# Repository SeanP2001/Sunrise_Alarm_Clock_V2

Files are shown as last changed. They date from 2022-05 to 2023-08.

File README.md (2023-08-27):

# Sunrise Alarm Clock V2

## Table of Contents

* [Introduction](#introduction)
* [Brief](#brief)
* [Method of Operation](#method-of-operation)
  + [Setup](#setup)
  + [Main Screen](#main-screen)
  + [Menu Layout](#menu-layout)
* [Circuitry](#circuitry)
  + [Schematic](#schematic)
  + [PCB Design](#pcb-design)
* [Enclosure](#enclosure)
  + [CAD Enclosure](#cad-enclosure)
  + [3D Printed Enclosure](#3d-printed-enclosure)
* [Demonstration](#demonstration)
* [Further Work](#further-work)

## Introduction

In my first year of university, I made a sunrise alarm clock for an assignment. Version 1 was a simple project using an Arduino Mega and an LCD keypad shield. [Here](https://github.com/SeanP2001/Arduino_Sunrise_Alarm_Clock) is a link to the repo for the original project. Over the past year and a half, I have developed my skills, so I decided to revisit this project.

## Brief

I wanted to design an alarm clock that uses light to wake me up naturally, making me feel more rested. However, I also needed an audio alarm to prevent me from solely relying on waking up naturally. Another feature I wanted to add was USB ports that could be switched on at time X and off at time Y. This would allow me to control USB-powered peripherals like lights, fans or a radio. I could also use these ports to charge devices without leaving them on charge all night.

## Method of Operation

### Setup

Before programming the alarm, you must put your Wi-Fi credentials in the "WifiCredentials.h" file.

```arduino
//------------------------ W I F I   C R E D E N T I A L S ------------------------

const char *ssid     = "YOUR_WIFI_SSID";        // REPLACE WITH YOUR WIFI SSID
const char *password = "YOUR_WIFI_PASSWORD";    // REPLACE WITH YOUR WIFI PASSWORD
```

When the alarm is first powered on, it will connect to your Wi-Fi to get the current date and time. It will then load any settings from EEPROM before it advances to the main screen (shown below).

### Main Screen

The alarm displays the day of the week and the current time on the main screen. There are also three icons. Unfortunately, the icons do not show up well in photos.

<p align="center">
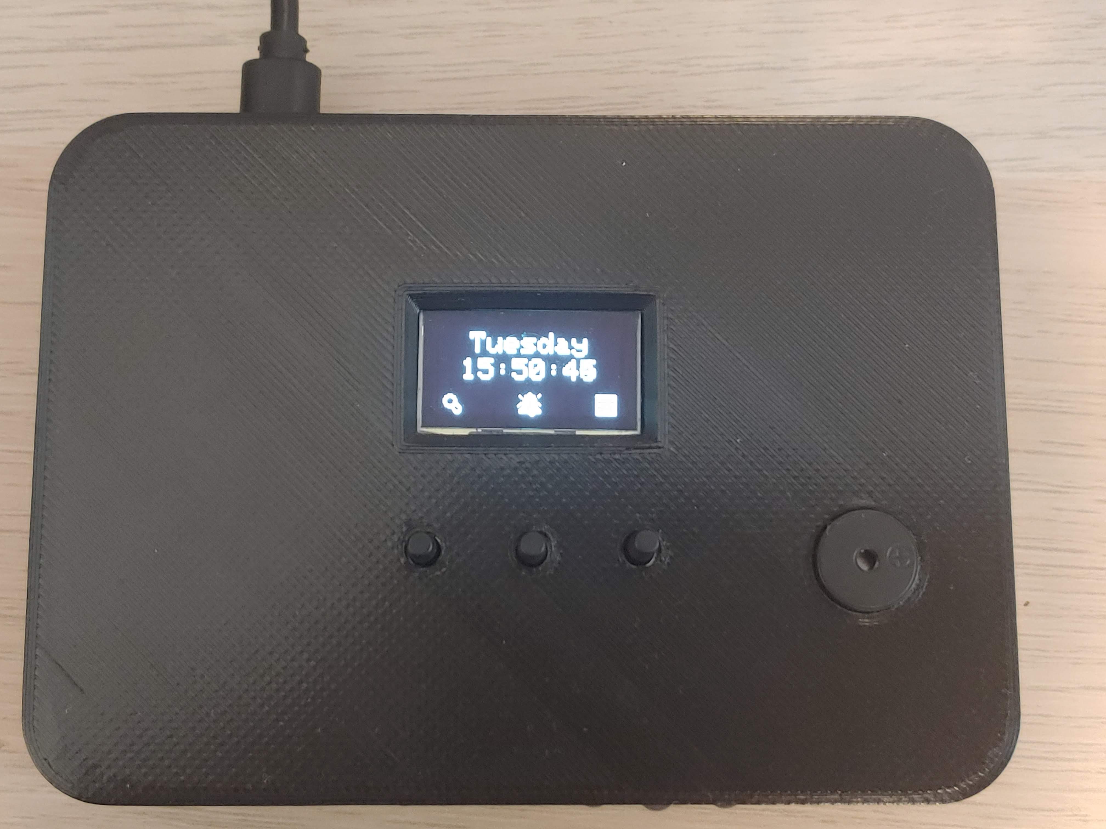
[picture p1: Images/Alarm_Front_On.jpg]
  
</p>

Pressing the left button will toggle the light bar on and off. When the light bar is on, the icon on the left (light bulb) changes to show it is on. When it is on, the bulb is shaded in, and when it is off, the icon is just an outline of a bulb. The light is a useful feature to help you see when you are getting into bed in the dark.

Pressing the middle button enables and disables the audio alarm. Pressing this button will cause the central icon (a bell) to change from being shaded in when the buzzer is enabled to an outline when it is disabled. If the alarm sounds, pressing the middle button will turn it off.

Pressing the right button enters the menu (shown below).

<p align="center">
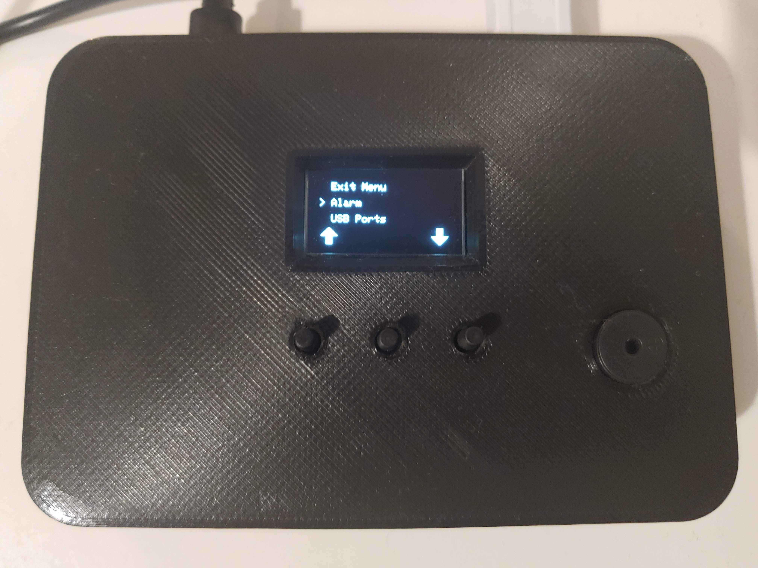
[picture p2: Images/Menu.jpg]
  
</p>

### Menu Layout

The menu has the following layout:

```
Main Menu
├── Alarm
│   ├── Light Bar
│   │   ├── On Time
│   │   └── Off Time
│   └── Buzzer
│       ├── On Time
│       └── Off Time
├── USB Ports
│   ├── USB 1
│   │   ├── On Time
│   │   └── Off Time
│   ├── USB 2
│   │   ├── On Time
│   │   └── Off Time
│   └── USB 3
│       ├── On Time
│       └── Off Time
├── Time
│   ├── Time Offset (hrs)
│   ├── Hours Between Syncs
│   └── Sync Time Now
└── Save
```

The "Alarm" settings allow you to alter when the light bar and buzzer automatically turn on and off. The "USB Ports" settings adjust when each port turns on and off.

In the "Time" menu, the "Time Offset" option allows you to set how many hours your time zone is ahead or behind UTC. The "Hours Between Syncs" option allows you to set how many hours the clock will run before it syncs to the time server again. "Sync Time Now" causes the alarm to reconnect to the Wi-Fi and connect to the time server to get the current time. This option is helpful if you have just altered the time offset and want to update the clock.

The "Save" option saves all of the settings to the EEPROM. This means you will not lose your settings when you turn the alarm off and back on again.

## Circuitry

### Schematic

<p align="center">
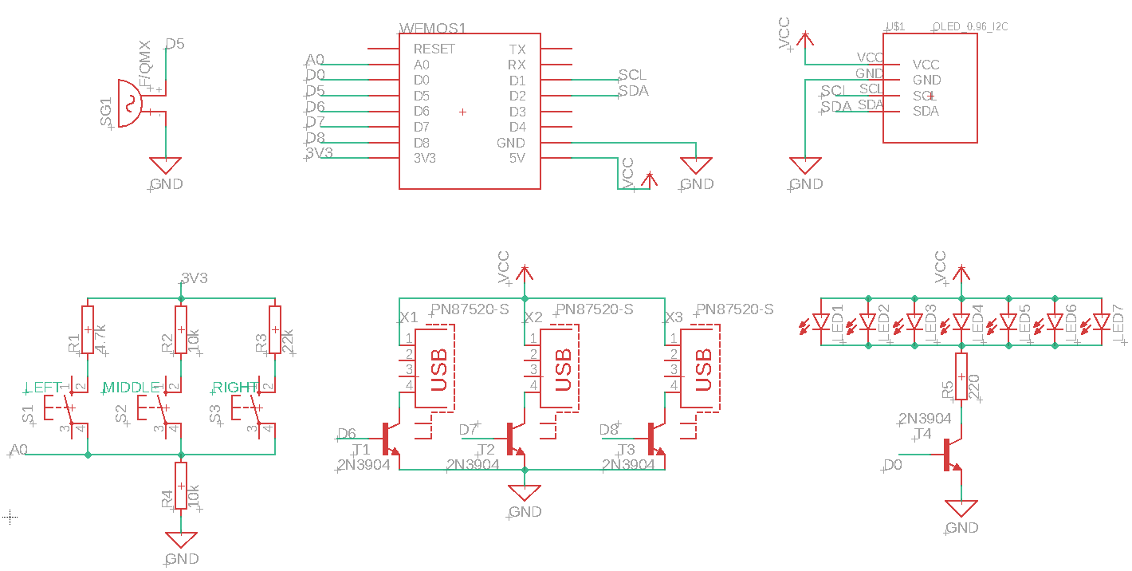
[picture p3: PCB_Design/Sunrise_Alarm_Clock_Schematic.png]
  
</p>

### PCB Design

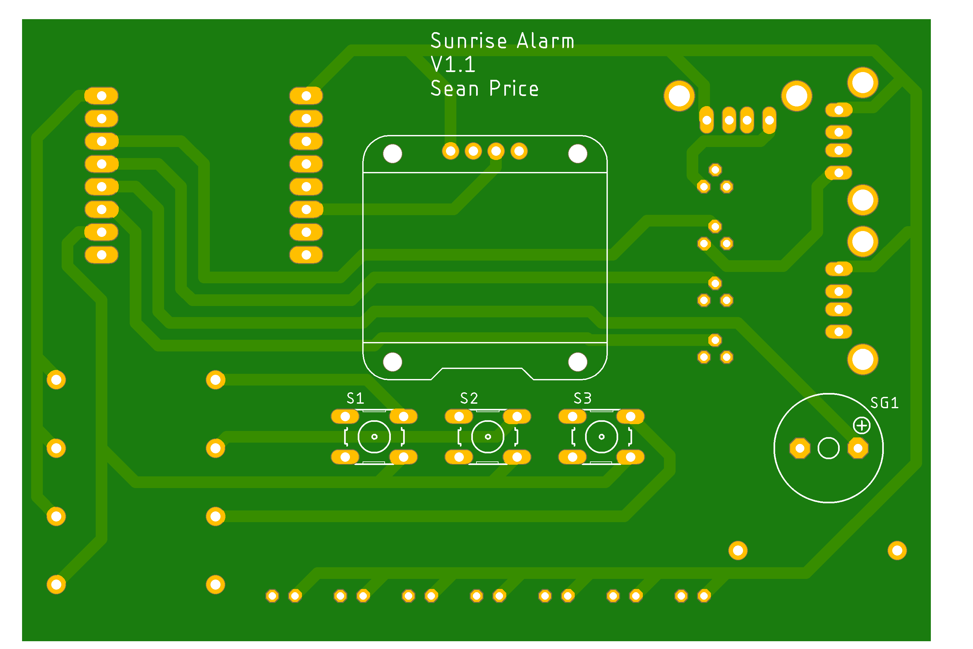
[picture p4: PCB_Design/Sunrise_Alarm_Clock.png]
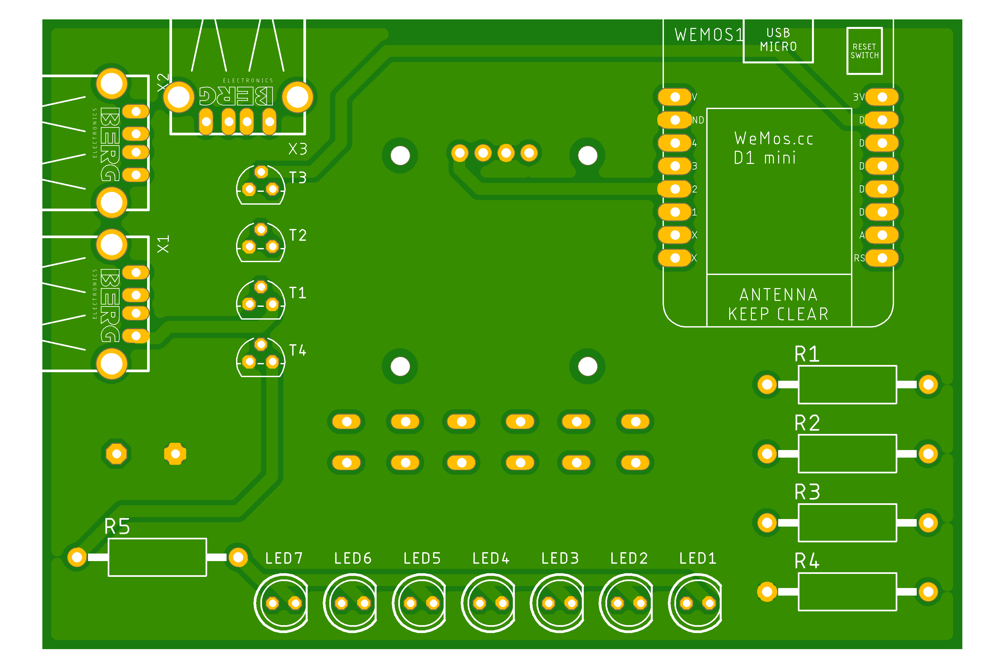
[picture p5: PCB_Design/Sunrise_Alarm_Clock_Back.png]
|  |  |
| --- | --- |
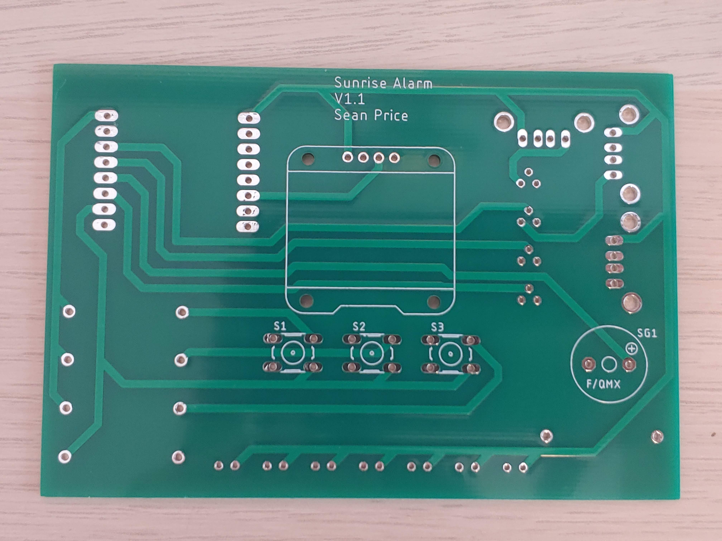
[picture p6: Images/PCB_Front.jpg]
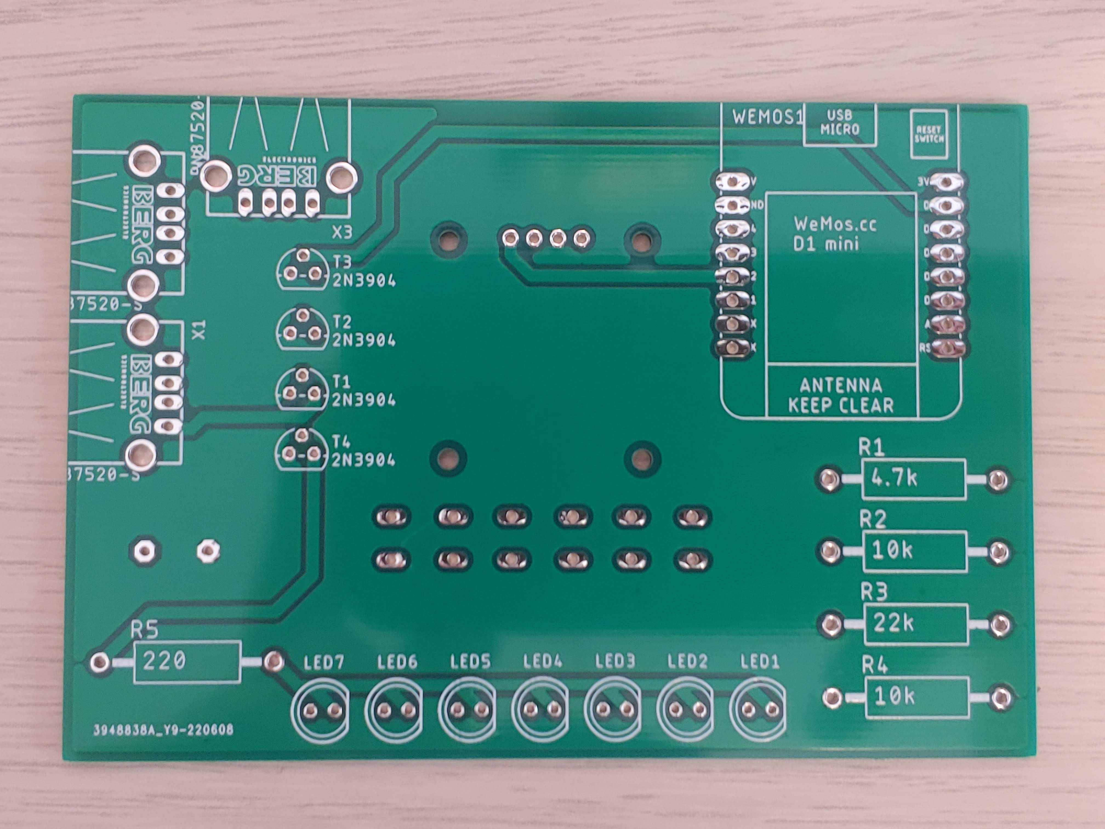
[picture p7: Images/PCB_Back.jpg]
|  |  |

## Enclosure

### CAD Enclosure

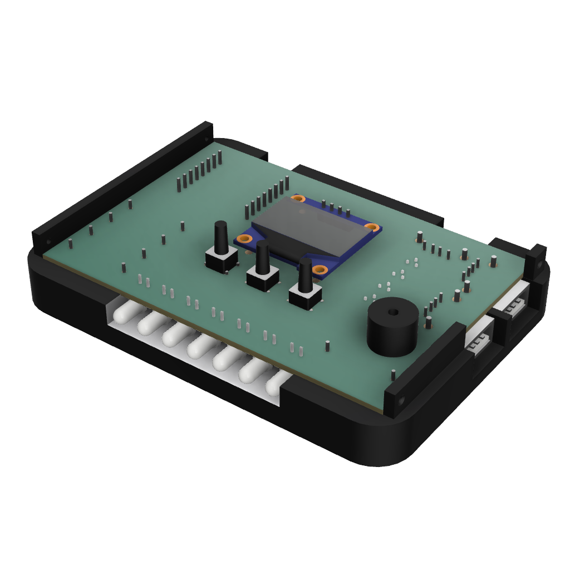
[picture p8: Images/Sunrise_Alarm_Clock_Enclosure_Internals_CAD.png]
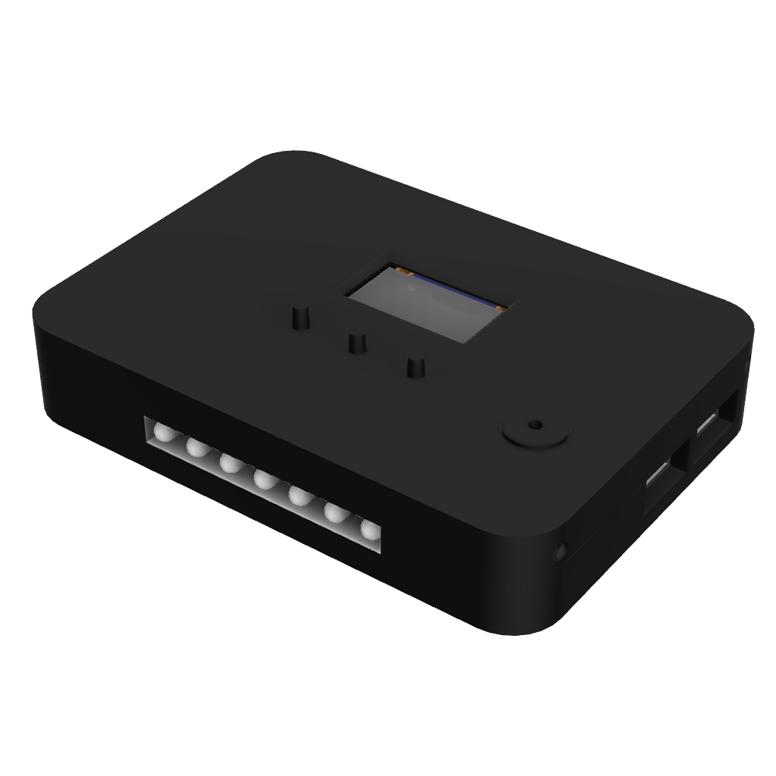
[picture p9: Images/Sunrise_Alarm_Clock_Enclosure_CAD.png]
|  |  |
| --- | --- |

### 3D Printed Enclosure

<p align="center">
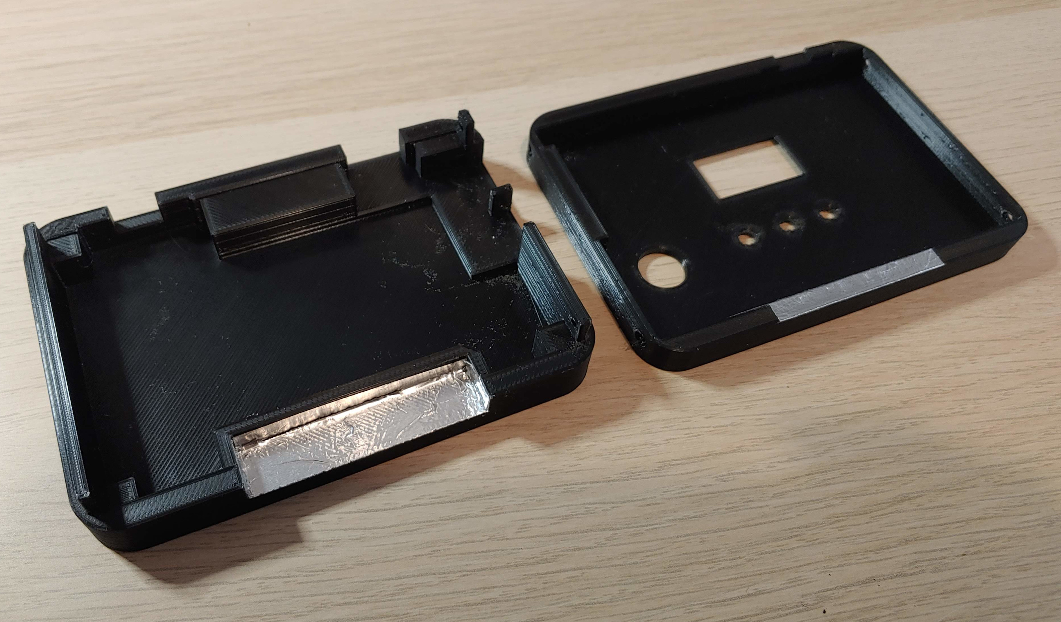
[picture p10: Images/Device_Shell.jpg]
  
</p>

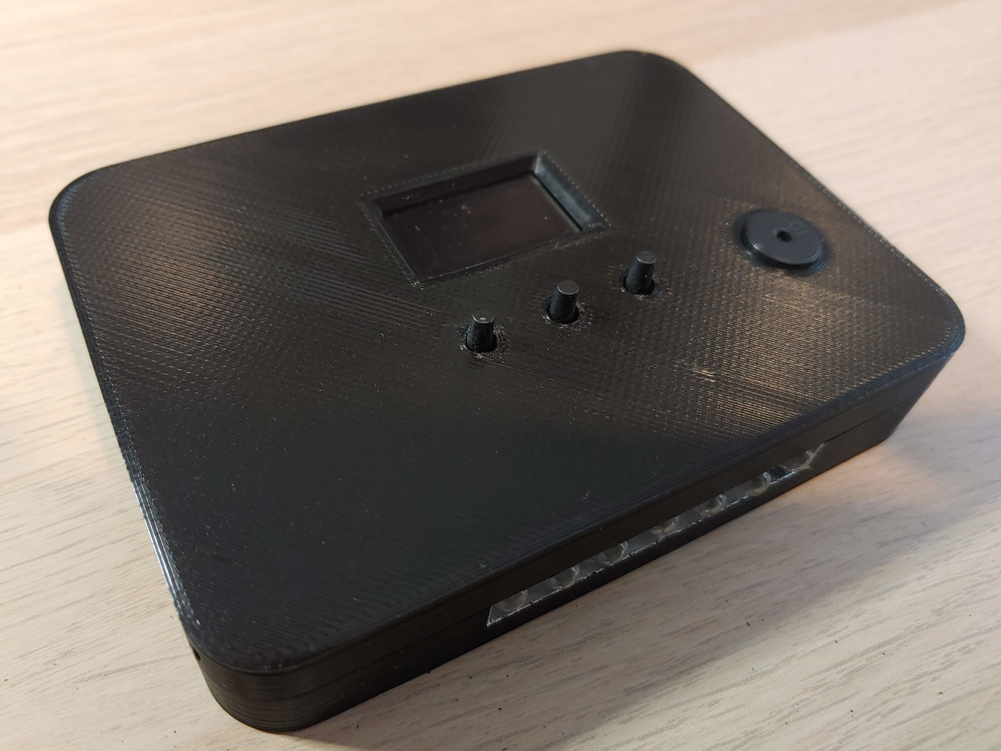
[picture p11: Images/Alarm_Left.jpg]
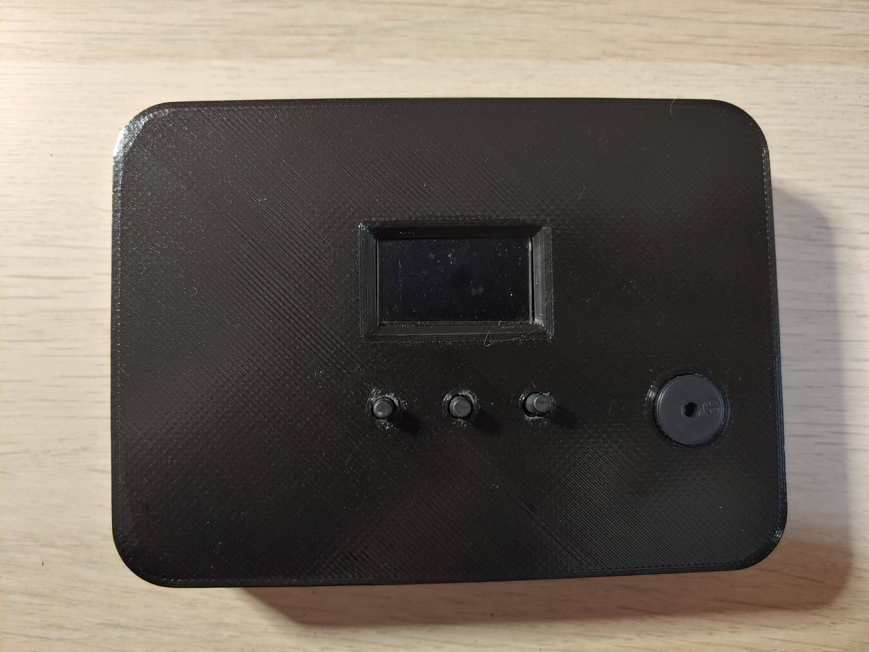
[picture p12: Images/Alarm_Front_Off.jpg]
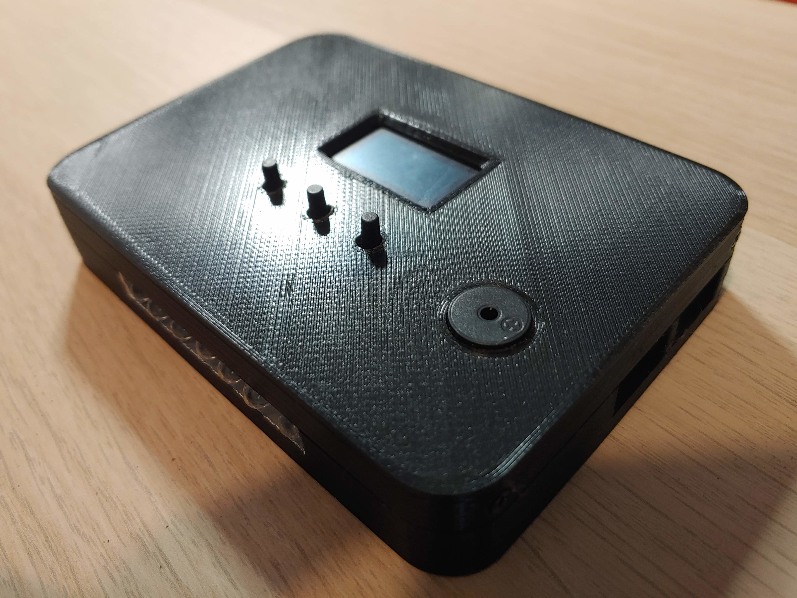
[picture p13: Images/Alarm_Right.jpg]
|  |  |  |
| --- | --- | --- |

## Demonstration

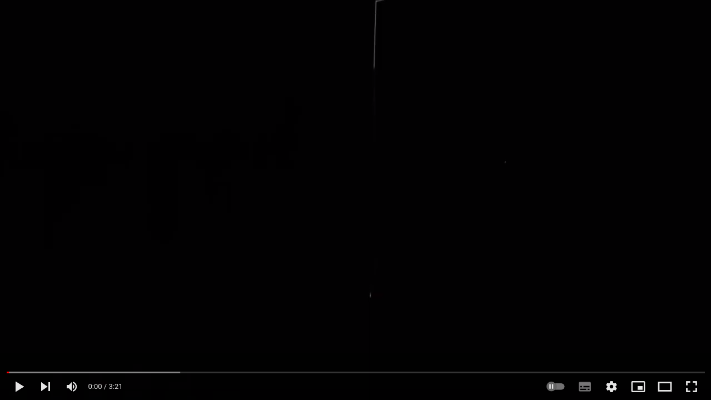
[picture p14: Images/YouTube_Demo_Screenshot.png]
Demo Video
[](https://www.youtube.com/watch?v=e8I5AvzANuw "Demo Video")

## Further Work

In future, I could;

- Create other wireless modules with which the alarm can communicate (windowsill light sensor, curtain motor, lamp).
- Add a weather icon to the main screen.
- Change the design to a more traditional alarm clock shape.
- Add a puzzle to switch off the alarm. This would prevent you from just hitting snooze.

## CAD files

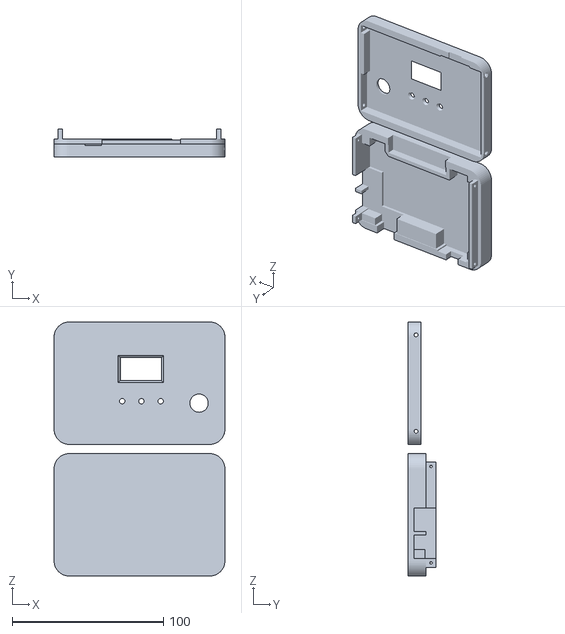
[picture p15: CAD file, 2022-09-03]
Enclosure/Sunrise_Alarm_Clock_Printable.stl
113.0 x 18.8 x 167.9

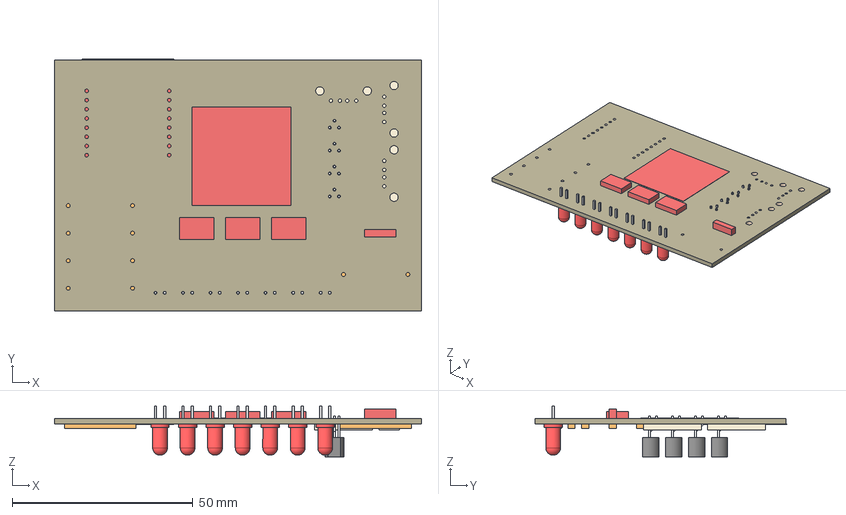
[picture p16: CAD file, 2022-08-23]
PCB_Design/3D_Models/Sunrise_Alarm_Clock_PCB.step
101.6 x 69.8 x 14.1 mm
Board
LED5MM x 7
B3F-10XX x 3
F/QMX
2N3904 x 4
OLED_0.96_I2C
WEMOS-D1-MINI
PN87520-S x 3

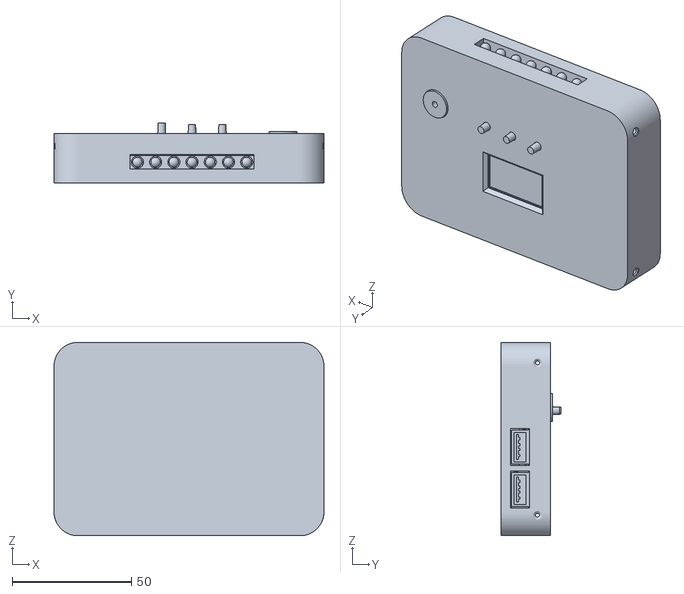
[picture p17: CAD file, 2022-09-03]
Enclosure/Sunrise_Alarm_Clock_Enclosure.stl
113.0 x 25.3 x 81.0

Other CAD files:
PCB_Design/3D_Models/Sunrise_Alarm_Clock_PCB.f3z

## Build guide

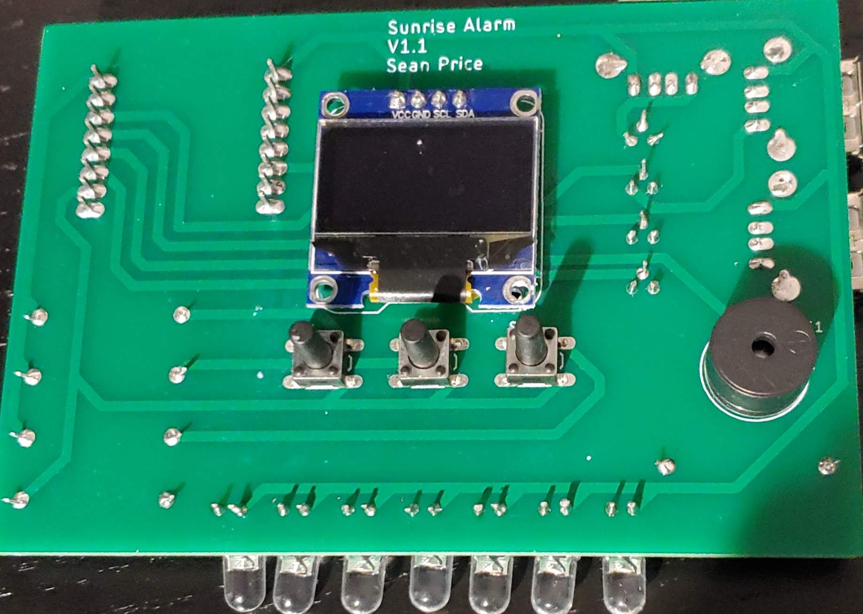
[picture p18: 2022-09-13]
Images/Soldered_PCB.jpeg

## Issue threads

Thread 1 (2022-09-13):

Navigating the Menu Crashes the Alarm Clock

SeanP2001, 2022-09-13:
The "Time" submenu appears to be broken. Sometimes it does not appear and moving past the "USB Ports" option crashes the clock and forces the device to restart. Other times the menu is visible but entering the "Time Between Syncs" setting will crash the device. Once in the "Time" submenu, selecting "Back" can also cause a crash.

Closed 2023-08-18.

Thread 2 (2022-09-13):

Currently Not Possible to Turn an Output On in the Evening and Off in the Morning

SeanP2001, 2022-09-13:
Currently, the logic is as follows:
```
if(hour(now()) >= deviceOnTime && hour(now()) < deviceOffTime)
{
     // Turn device on
}
```
This works perfectly if you want the light bar to turn on at 7 AM and turn back off at 8 AM. This is because (7 <= hour < 8) works. It is possible for the current hour to be between 7 and 8.

However, if you want a USB port to charge your phone between 11 PM and 2 AM it will not work. This is because (23 <= hour < 2) doesn't work. The current hour will never be more than or equal to 23 and also less than 2.

Closed 2023-08-29.

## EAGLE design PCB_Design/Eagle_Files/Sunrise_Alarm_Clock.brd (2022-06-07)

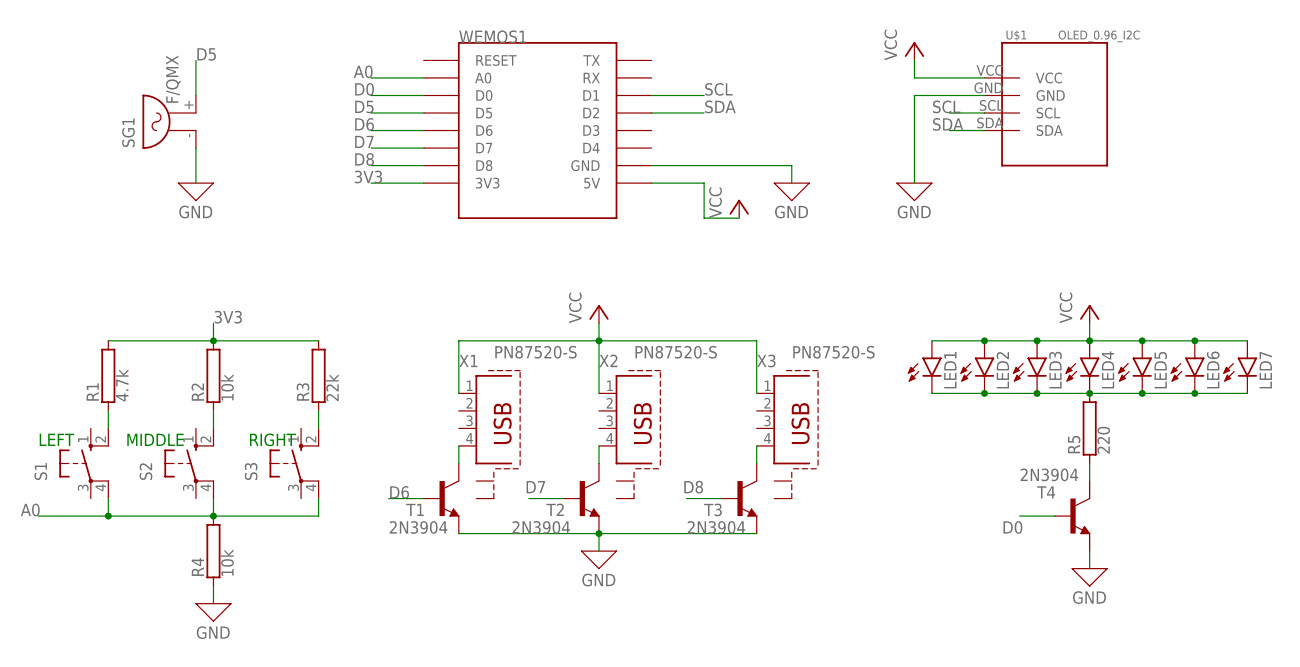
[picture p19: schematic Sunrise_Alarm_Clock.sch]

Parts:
LED1, LED2, LED3, LED4, LED5, LED6, LED7: LED5MM
R1: 4.7k; AC01
R2, R4: 10k; AC01
R3: 22k; AC01
R5: 220; AC01
S1, S2, S3: 10-XX; B3F-10XX
SG1: F/QMX
T1, T2, T3, T4: 2N3904; TO92
U$1: OLED_0.96_I2C
WEMOS1: WEMOS-D1-MINI
X1, X2, X3: PN87520-S

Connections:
3V3: R1.2, R2.2, R3.2, WEMOS1.3V3
A0: R4.2, S1.4 (P1), S2.4 (P1), S3.4 (P1), WEMOS1.A0
D0: T4.2 (B), WEMOS1.D0
D5: SG1.+ (2), WEMOS1.D5
D6: T1.2 (B), WEMOS1.D6
D7: T2.2 (B), WEMOS1.D7
D8: T3.2 (B), WEMOS1.D8
GND: R4.1, SG1.- (1), T1.3 (E), T2.3 (E), T3.3 (E), T4.3 (E), U$1.GND, WEMOS1.GND
unnamed: T3.1 (C), X3.4
unnamed: T2.1 (C), X2.4
unnamed: T1.1 (C), X1.4
unnamed: R3.1, S3.2 (S1)
unnamed: R2.1, S2.2 (S1)
unnamed: R1.1, S1.2 (S1)
unnamed: R5.1, T4.1 (C)
unnamed: LED1.K (C), LED2.K (C), LED3.K (C), LED4.K (C), LED5.K (C), LED6.K (C), LED7.K (C), R5.2
SCL: U$1.SCL, WEMOS1.D1
SDA: U$1.SDA, WEMOS1.D2
VCC: LED1.A, LED2.A, LED3.A, LED4.A, LED5.A, LED6.A, LED7.A, U$1.VCC, WEMOS1.5V, X1.1, X2.1, X3.1

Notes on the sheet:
LEFT
MIDDLE
RIGHT

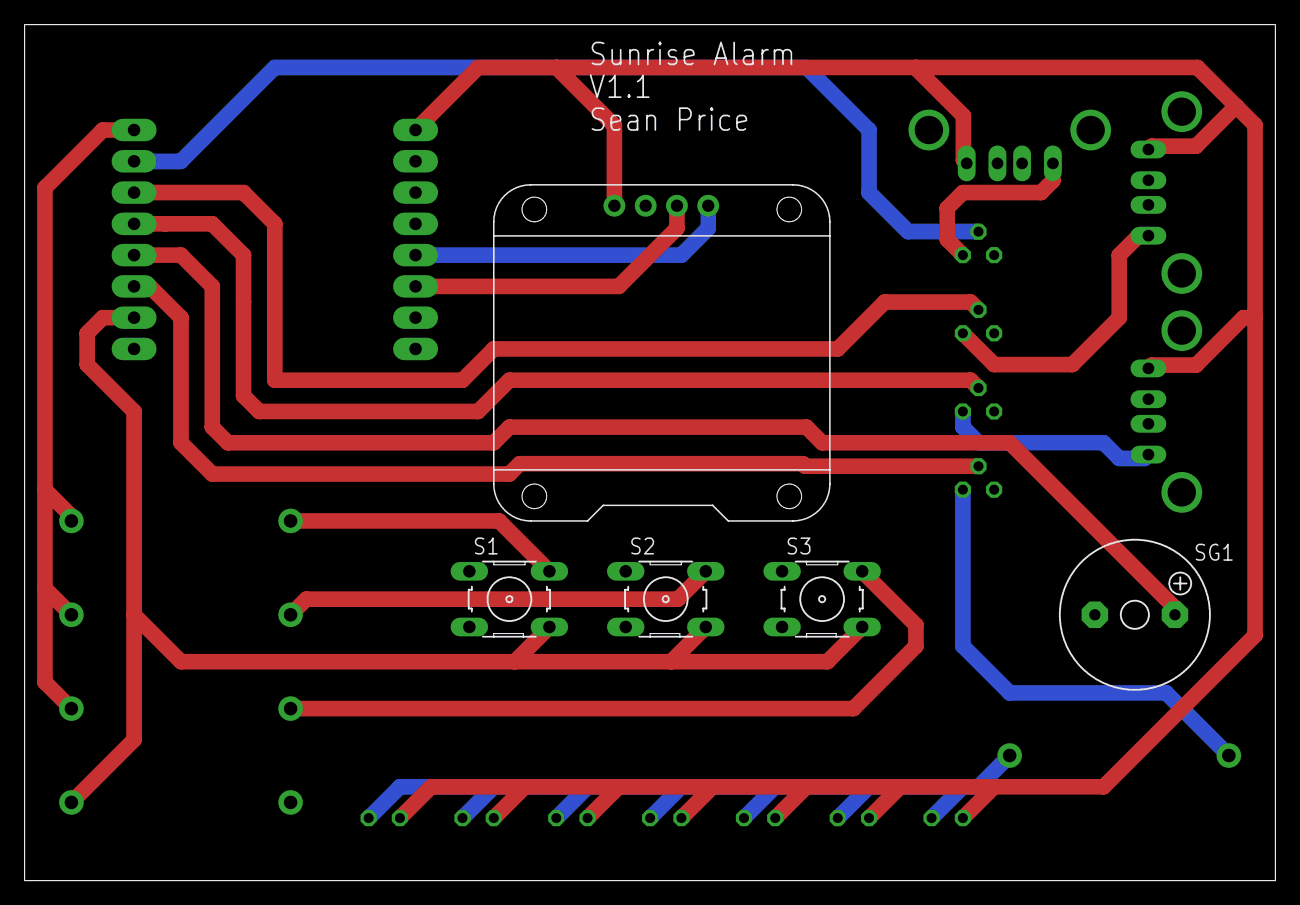
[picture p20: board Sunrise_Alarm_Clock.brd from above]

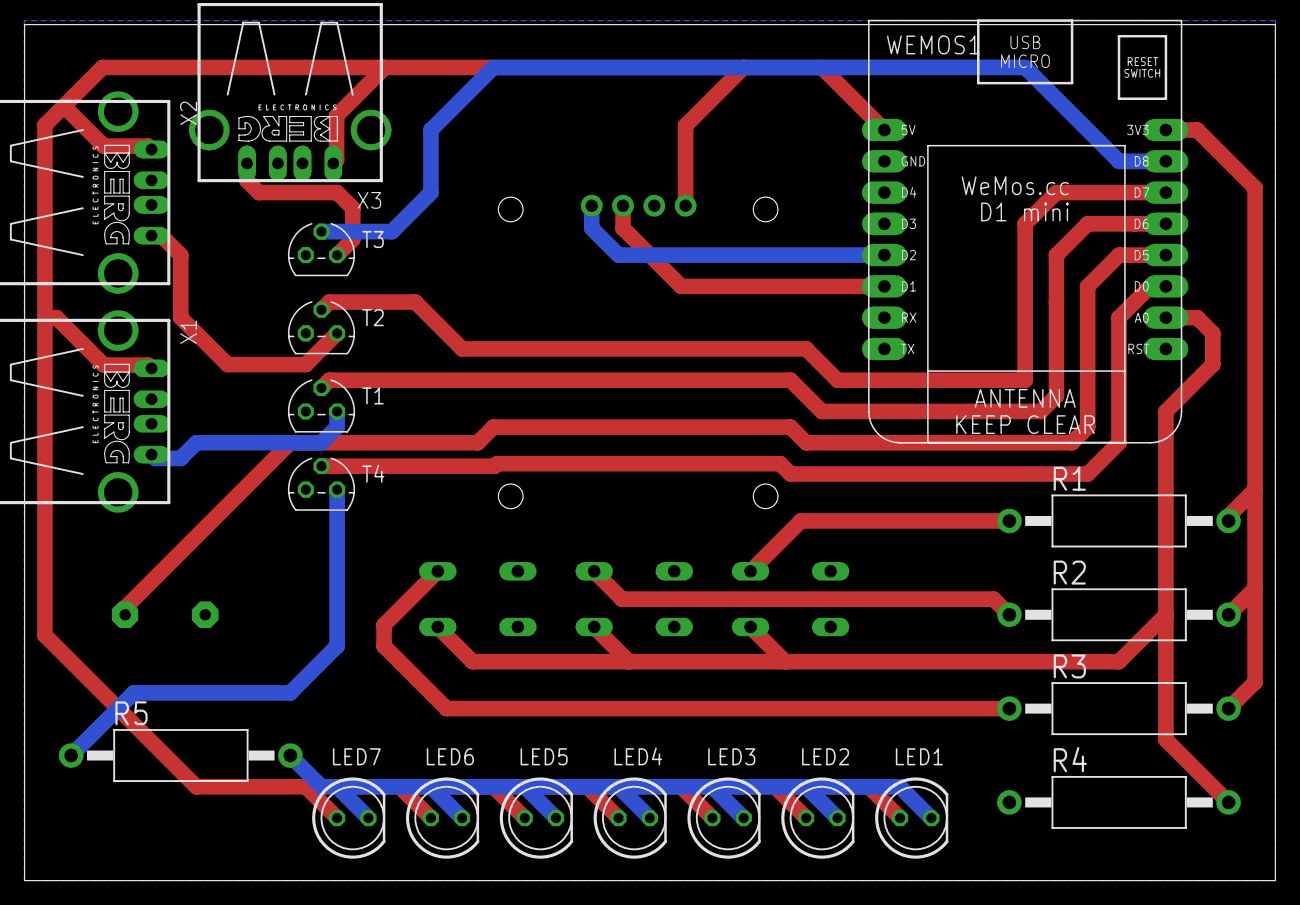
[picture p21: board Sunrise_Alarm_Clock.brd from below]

Board: 2 copper layers, 101.6 x 69.5 mm, 25 parts (20 on the bottom side), 19 nets.

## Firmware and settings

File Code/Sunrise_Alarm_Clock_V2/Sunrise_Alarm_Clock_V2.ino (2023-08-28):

//-----------------------------------------------------------------------------------------------------------------------------------
// Sunrise Alarm Clock V2
// Sean Price
//-----------------------------------------------------------------------------------------------------------------------------------

#include <TimeLib.h>
#include <NTPClient.h>
#include <ESP8266WiFi.h>
#include <WiFiUdp.h>

#include <SPI.h>
#include <Wire.h>
#include <Adafruit_GFX.h>
#include <Adafruit_SSD1306.h>

#include "Button.h"

#include "SettingsManager.h"
#include "DisplayManager.h"

#include "MenuItem.h"
#include "Menu.h"
#include "Stack.h"

#include "Light.h"
#include "USB.h"
#include "Alarm.h"

#include "WifiCredentials.h"

//----------------------------------------------------------- P I N O U T -----------------------------------------------------------

#define buttonsPin A0
#define lightBarPin D0
#define buzzerPin D5
#define usb1Pin D6
#define usb2Pin D7
#define usb3Pin D8

//---------------------------------------------------------- B U T T O N S ----------------------------------------------------------
                     //***** Button obj(Pin, AnalogValue, Tolerance) ******//
Button left(buttonsPin, 700, 100);          
Button middle(buttonsPin, 500, 100);
Button right(buttonsPin, 300, 100);

//---------------------------------------------------------- D E V I C E S ----------------------------------------------------------

Light lightBar(lightBarPin);
USB usb1(usb1Pin);
USB usb2(usb2Pin);
USB usb3(usb3Pin);

Alarm alarm(buzzerPin);

//------------------------------------------------ D I S P L A Y   V A R I A B L E S ------------------------------------------------  

#define SCREEN_WIDTH 128                                                    // OLED display width, in pixels
#define SCREEN_HEIGHT 64                                                    // OLED display height, in pixels
#define OLED_RESET     -1                                                   // Reset pin # (or -1 if sharing Arduino reset pin)
const uint8_t SCREEN_ADDRESS = 0x3C;                                        // See datasheet for Address
Adafruit_SSD1306 display(SCREEN_WIDTH, SCREEN_HEIGHT, &Wire, OLED_RESET);   // Instantiate OLED Display

uint8_t screenTimeoutStart = 22;                                            // The screen will be able to timeout from 22:00
uint8_t screenTimeoutEnd = 7;                                               // to 07:00
uint8_t inactivityTimeout = 1;                                              // The duration of inactivity (in minutes) before the screen goes blank

bool screenIsOn = true;                                                     // turns the display on or off

//-------------------------------------------- T I M E   &   D A T E   V A R I A B L E S --------------------------------------------

uint8_t nextSyncHour = 0;                   // Variable to store the next hour when the clock needs to be synced

// Define NTP Client to get time
WiFiUDP ntpUDP;
NTPClient timeClient(ntpUDP, "pool.ntp.org", 0);

uint8_t ntpConnectionTimeout = 30;          // How many seconds before giving up connecting to the NTP server   


//----------------------------------------------- S E T T I N G S   V A R I A B L E S -----------------------------------------------

Settings currentSettings = {
    .lightBarOnTime = 0,
    .lightBarOffTime = 0,

    .buzzerOnTime = 0,
    .buzzerOffTime = 0,

    .usb1OnTime = 0,
    .usb1OffTime = 0,

    .usb2OnTime = 0,
    .usb2OffTime = 0,

    .usb3OnTime = 0,
    .usb3OffTime = 0,

    .utcOffset = 1,               // How many hours ahead or behind of UTC (BST=1 & GMT=0)
    .hrsBetweenSync = 12          // How often the clock needs to be synced (hours)
};

//------------------------------------------------------------- M E N U -------------------------------------------------------------

MenuItem* currentMenu = mainMenu;                                   // By default the main menu is selected as the current menu
uint8_t selectedIndex = 0;                                          // By default the first item on the menu is selected with the cursor

Stack parentMenuStack;                                              // A stack containing all of the parent menus (enables back navigation)

bool menuIsOpen = false;

enum Direction{LEFT, RIGHT};

//------------------------------------------------------------ S E T U P ------------------------------------------------------------

void setup()
{
  Serial.begin(115200);

  EEPROM.begin(512);

  loadSettings(currentSettings);                         // Load settings from EEPROM
  updateDevices(currentSettings);                        // Update all the device objects to reflect the current settings

  displayInit();                                         // Initialise the Display
  
  syncTime();                                            // Sync the local time to the NTP server
  calcNextSync(now(), currentSettings);                  // Calculate when the clock will next need to be synced

  if(itIsNight(now()))                                   // if it is night
  {
    resetScreenTimeout(now());                           // set the screen to timeout in 1 minute (default)
  }                   
}


//------------------------------------------------------------- M A I N -------------------------------------------------------------

void loop() 
{  
  manageScreenTimeout(now());                                 // Manage the screen timeout depending on the time of day
  manageOutputs(now());                                       // Turn on or off the light bar, buzzer or USB ports depending on the time

  if(screenIsOn)                                         // If the screen is on
  {
    displayTime(now());                                        // display the time
    displayIcons(menuIsOpen, lightBar.isOn(), alarm.isEnabled());  // and the icons

    if(left.buttonIsPressed())                             // Pressing the left button toggles the light bar on or off
    {
      lightBar.toggle();
      resetScreenTimeout(now());
    }

    if(middle.buttonIsPressed())                           // pressing the middle button enables and disables the buzzer 
    {      
      alarm.toggle();
      resetScreenTimeout(now());
    }

    if(right.buttonIsPressed())                            // Pressing the right button opens the menu
    {
      openMenu();
    }
  }
  else
  {
    displayBlankScreen();                                                           // make the screen blank 
  }



  while(menuIsOpen)                                           // When the menu is open
  {
    displayIcons(menuIsOpen, lightBar.isOn(), alarm.isEnabled());
    
    if(left.buttonIsPressed())                                // Pressing the left button moves the cursor to the previous item
    {
      navigateMenu(LEFT);
    }
    
    if(middle.buttonIsPressed())                              // Pressing the middle button selects the item highlighted by the cursor
    {
      handleMenuItem();
    }

    if(right.buttonIsPressed())                               // Pressing the right button moves the cursor to the next item (if there is one)
    {
      navigateMenu(RIGHT);
    }
    
    delay(100);
  }

  
  if(hour(now()) == nextSyncHour)                        // If the local clock needs to be synced
  {
    syncTime();                                          // Sync the local time to the NTP server

    nextSyncHour = calcNextSync(now(), currentSettings); // and calculate when the clock will next need to be synced
  }

  delay(100);
}

//-------------------------------------------------------- O P E N   M E N U --------------------------------------------------------
void openMenu()
{
  displayMenuSplashscreen();   
  delay(1000);                       
  menuIsOpen = true; 
  currentMenu = mainMenu;                              // By default the main menu is selected as the current menu
  selectedIndex = 0;                                   // By default the first item on the menu is selected with the cursor
  displayMenu(currentMenu, selectedIndex);
}
//------------------------------------------------- H A N D L E   M E N U   I T E M -------------------------------------------------
void handleMenuItem()
{
  enum FunctionID selectedSetting = currentMenu[selectedIndex].functionID;

  switch(selectedSetting)
  {
    case EXIT:
      closeMenu();
      break;

    case BACK:
      goToParentMenu();
      break;

    case SUBMENU:
      goToSubMenu();
      break;

    case SYNC_TIME_NOW:
      syncTime();                                               // Sync the local time to the NTP server
      calcNextSync(now(), currentSettings);                     // Calculate when the clock will next need to be synced
      break;

    case SAVE:
      saveSettingsAndDisplayMessage();
      break;

    default:
      displayBlankScreen();
      adjustSetting(selectedSetting, currentSettings);
      break;
  }

  if(menuIsOpen)                                          // If the menu is still open
  {
    displayMenu(currentMenu, selectedIndex);              // display the menu
  }
}


//---------------------------------------------------- N A V I G A T E   M E N U ----------------------------------------------------
void navigateMenu(enum Direction direction)
{
  if(direction == LEFT)
  {
    if(selectedIndex > 0)
    {
      selectedIndex--;
    }
  
    displayMenu(currentMenu, selectedIndex);
  }
  if(direction == RIGHT)
  {
    if(currentMenu[selectedIndex + 1].functionID != END_MARKER) 
    {
      selectedIndex++;
    }
  
    displayMenu(currentMenu, selectedIndex);
  }
}

//------------------------------------------------------- C L O S E   M E N U -------------------------------------------------------
void closeMenu()
{
  menuIsOpen = false;
  screenTimeoutMin = minute(now()) + 1;
  screenTimeoutSec = second(now());
  displayBlankScreen();
}

//------------------------------------------------ G O   T O   P A R E N T   M E N U ------------------------------------------------
void goToParentMenu()
{
  currentMenu = parentMenuStack.peek();
  parentMenuStack.pop();
  selectedIndex = 0;
}

//--------------------------------------------------- G O   T O   S U B   M E N U ---------------------------------------------------
void goToSubMenu()
{
  parentMenuStack.push(currentMenu);
  currentMenu = currentMenu[selectedIndex].subMenu;
  selectedIndex = 0;
}

//-------------------------------- S A V E   S E T T I N G S   A N D   D I S P L A Y   M E S S A G E --------------------------------
void saveSettingsAndDisplayMessage()
{
  displaySavingScreen();
  saveSettings(currentSettings);
  delay(1000);
  displaySavedScreen();
  delay(1000);
  displayBlankScreen();
}

//-------------------------------------------------------- S Y N C   T I M E --------------------------------------------------------

void syncTime()
{
  WiFi.mode(WIFI_STA);                              // Turn the WiFi on  
  WiFi.begin(ssid, password);                    

  display.clearDisplay();                           // Clear the Display
  display.setTextSize(2);
  display.setTextColor(WHITE, BLACK);
  display.setCursor(0,0);
  display.println("Connecting");                    // Show that the device is connecting to the WiFi
  display.display();


  for ( int sec = 0; (WiFi.status() != WL_CONNECTED) && (sec < ntpConnectionTimeout); sec++)  // Until the WiFi Connects or times out
  {  
    display.print(".");                             // Put dots on the screen to show it hasn't frozen
    display.display();
    delay (1000);
  }

  display.clearDisplay();                           // Clear the Display 
  display.setCursor(0,0);

  if(WiFi.status() == WL_CONNECTED)                 // If the WiFi has successfully connected
  {
    display.println("Connected");                   // Show that the alarm has connected to the WiFi
    display.display();
    delay(2000);

    timeClient.begin();                             // Connect to the NTP Server
    timeClient.update();                            // Get the time from the NTP Server

    String formattedDate = timeClient.getFormattedDate(); // FORMAT 2020-08-14T19:26:35Z

    String yearStr = formattedDate.substring(0, 4);       // Extract year and convert it to an int
    int year;
    year = yearStr.toInt();
      
    String monthStr = formattedDate.substring(5, 7);      // Extract month and convert it to an int
    int month;
    month = monthStr.toInt();

    String dayStr = formattedDate.substring(8, 10);       // Extract day and convert it into an int
    int day;
    day = dayStr.toInt();

    setTime(timeClient.getHours() + currentSettings.utcOffset, timeClient.getMinutes(), timeClient.getSeconds(), day, month, year); // Set the local time
  }
  else                                              // If the WiFi has failed to connect
  {
    display.println("Connection");                  // Show that the alarm has failed to connect to the WiFi
    display.println("Failed"); 
    display.display();
    delay(2000);
  }

  displayBlankScreen();
    
  WiFi.mode(WIFI_OFF);                              // Turn off the WiFi

}

//---------------------------------------------- C A L C U L A T E   N E X T   S Y N C ----------------------------------------------

uint8_t calcNextSync(time_t t, const Settings &settings)
{
  return (hour(t) + settings.hrsBetweenSync) % 24;      // Add to the current hour to find when the clock next needs to sync
}



//--------------------------------------------------- M A N A G E   O U T P U T S ---------------------------------------------------

void manageOutputs(time_t t)
{
  lightBar.manageOutput(t);         // Turn on the light bar when it is scheduled                    
  
  alarm.manageOutput(t);            // Sound the audio alarm when it is scheduled                
  
  usb1.manageOutput(t);             // Turn on USB port 1 when it is scheduled                     

  usb2.manageOutput(t);             // Turn on USB port 2 when it is scheduled                     

  usb3.manageOutput(t);             // Turn on USB port 3 when it is scheduled                     
}

//--------------------------------------------------- A D J U S T   S E T T I N G ---------------------------------------------------

void adjustSetting(FunctionID functionID, Settings &currentSettings) 
{
  delay(500);

  while (!middle.buttonIsPressed()) 
  {
    displaySetting(functionID, currentSettings);

    if (left.buttonIsPressed()) 
    {
      switch (functionID) {
        case LIGHT_BAR_ON_TIME:
          if (currentSettings.lightBarOnTime > 0) {
            currentSettings.lightBarOnTime--;
          }
          break;
        case LIGHT_BAR_OFF_TIME:
          if (currentSettings.lightBarOffTime > 0) {
            currentSettings.lightBarOffTime--;
          }
          break;
        case BUZZER_ON_TIME:
          if (currentSettings.buzzerOnTime > 0) {
            currentSettings.buzzerOnTime--;
          }
          break;
        case BUZZER_OFF_TIME:
          if (currentSettings.buzzerOffTime > 0) {
            currentSettings.buzzerOffTime--;
          }
          break;
        case USB_1_ON_TIME:
          if (currentSettings.usb1OnTime > 0) {
            currentSettings.usb1OnTime--;
          }
          break;
        case USB_1_OFF_TIME:
          if (currentSettings.usb1OffTime > 0) {
            currentSettings.usb1OffTime--;
          }
          break;
        case USB_2_ON_TIME:
          if (currentSettings.usb2OnTime > 0) {
            currentSettings.usb2OnTime--;
          }
          break;
        case USB_2_OFF_TIME:
          if (currentSettings.usb2OffTime > 0) {
            currentSettings.usb2OffTime--;
          }
          break;
        case USB_3_ON_TIME:
          if (currentSettings.usb3OnTime > 0) {
            currentSettings.usb3OnTime--;
          }
          break;
        case USB_3_OFF_TIME:
          if (currentSettings.usb3OffTime > 0) {
            currentSettings.usb3OffTime--;
          }
          break;
        case TIME_OFFSET:
          if (currentSettings.utcOffset > -12) {
            currentSettings.utcOffset--;
          }
          break;
        case HOURS_BETWEEN_SYNCS:
          if (currentSettings.hrsBetweenSync > 1) {
            currentSettings.hrsBetweenSync--;
          }
          break;
      }

      updateDevices(currentSettings);         // Update all the device objects to reflect the current settings
    }

    if (right.buttonIsPressed()) 
    {
      switch (functionID) {
        case LIGHT_BAR_ON_TIME:
          if (currentSettings.lightBarOnTime < 23) {
            currentSettings.lightBarOnTime++;
          }
          break;
        case LIGHT_BAR_OFF_TIME:
          if (currentSettings.lightBarOffTime < 23) {
            currentSettings.lightBarOffTime++;
          }
          break;
        case BUZZER_ON_TIME:
          if (currentSettings.buzzerOnTime < 23) {
            currentSettings.buzzerOnTime++;
          }
          break;
        case BUZZER_OFF_TIME:
          if (currentSettings.buzzerOffTime < 23) {
            currentSettings.buzzerOffTime++;
          }
          break;
        case USB_1_ON_TIME:
          if (currentSettings.usb1OnTime < 23) {
            currentSettings.usb1OnTime++;
          }
          break;
        case USB_1_OFF_TIME:
          if (currentSettings.usb1OffTime < 23) {
            currentSettings.usb1OffTime++;
          }
          break;
        case USB_2_ON_TIME:
          if (currentSettings.usb2OnTime < 23) {
            currentSettings.usb2OnTime++;
          }
          break;
        case USB_2_OFF_TIME:
          if (currentSettings.usb2OffTime < 23) {
            currentSettings.usb2OffTime++;
          }
          break;
        case USB_3_ON_TIME:
          if (currentSettings.usb3OnTime < 23) {
            currentSettings.usb3OnTime++;
          }
          break;
        case USB_3_OFF_TIME:
          if (currentSettings.usb3OffTime < 23) {
            currentSettings.usb3OffTime++;
          }
          break;
        case TIME_OFFSET:
          if (currentSettings.utcOffset < 12) {
            currentSettings.utcOffset++;
          }
          break;
        case HOURS_BETWEEN_SYNCS:
          if (currentSettings.hrsBetweenSync < 24) {
            currentSettings.hrsBetweenSync++;
          }
          break;
      }
      updateDevices(currentSettings);           // Update all the device objects to reflect the current settings
    }

    delay(100);
  }

  displayBlankScreen();                         // Clear the Display when the user exits the screen
}


//--------------------------------------------------- U P D A T E   D E V I C E S ---------------------------------------------------
void updateDevices(const Settings &settings)
{
  lightBar.setOnTime(settings.lightBarOnTime);          // Set the on time of the device based on the setting
  lightBar.setOffTime(settings.lightBarOffTime);

  usb1.setOnTime(settings.usb1OnTime);
  usb1.setOffTime(settings.usb1OffTime);

  usb2.setOnTime(settings.usb2OnTime);
  usb2.setOffTime(settings.usb2OffTime);

  usb3.setOnTime(settings.usb3OnTime);
  usb3.setOffTime(settings.usb3OffTime);

  alarm.setOnTime(settings.buzzerOnTime);
  alarm.setOffTime(settings.buzzerOffTime);
}

//------------------------------------------------------ I T   I S   N I G H T ------------------------------------------------------

bool itIsNight(time_t t)
{
  return (hour(t) >= screenTimeoutStart || hour(t) < screenTimeoutEnd);               // At night (22:00-07:00 by default)
}

//-------------------------------------------- A N Y   B U T T O N   I S   P R E S S E D --------------------------------------------

bool anyButtonIsPressed()
{
  return (left.buttonIsPressed() || middle.buttonIsPressed() || right.buttonIsPressed());
}

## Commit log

2022-03-23 V2.1.0-alpha Added PCB design files
    [Sunrise_Alarm_Clock.brd, Sunrise_Alarm_Clock.sch]
2022-05-28 V2.1.1-alpha PCB V1.1
    - Placed LEDs, USBs and D1 mini on the rear of the board
    - Changed USB footprint to include shield pads
    - Fixed transistors to be common-emitter
    - Broke schematic into sections to make it easier to follow
    - Hand-routed thicker traces
    [Sunrise_Alarm_Clock.brd, Sunrise_Alarm_Clock.sch]
2022-05-29 V2.1.2-alpha Generated gerber files showing silkscreen component values
2022-06-07 V2.1.3-alpha Finalised PCB V1.1
    [Sunrise_Alarm_Clock.brd]
2022-08-23 V2.2.0-alpha Created a 3D Model of the populated PCB
    [Sunrise_Alarm_Clock.brd, Sunrise_Alarm_Clock.sch, Sunrise_Alarm_Clock_PCB.f3z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]
2022-08-23 V2.2.1-alpha Designed an Enclosure
    [Sunrise_Alarm_Clock_Enclosure.stl, Sunrise_Alarn_Clock_Printable.stl]
2022-08-23 V2.2.2-alpha Fixed a Typo
    [Sunrise_Alarm_Clock_Printable.stl]
2022-09-03 V2.2.3-alpha Modified the Enclosure to be Stronger
    [Sunrise_Alarm_Clock_Enclosure.stl, Sunrise_Alarm_Clock_Printable.stl]
2022-09-03 V2.2.4-alpha Separated the Parts in the Printable File
    [Sunrise_Alarm_Clock_Printable.stl]
2022-09-06 V2.4.0-alpha Added the Button Class and Added Night Light Functionality
2022-09-12 V2.7.1-alpha Fixed Bug Preventing Automatic Screen Timeout
    Previously the screen would not turn off at night unless you pressed a button. It would then timeout 1 minute later. The screen also did not turn back on in the morning without pressing a button.
    Now the screen will automatically turn off at 10PM and turn back on at 7AM. During this period pressing a button will turn the screen back on before it times out a minute later.
    [Sunrise_Alarm_Clock_V2.ino]
2022-09-12 V2.7.2-alpha Fixed Bug Preventing Outputs Turning On During Night Hours
    Previously none of the outputs could be turned on or off automatically during the night hours (22:00-07:00). This meant that if you set the light bar to turn on at 6AM, it would not turn on unless you pressed a button to turn the screen back on.
    Now all of the outputs can be switched on and off regardless of the time of day or whether the screen is on or off.
    [Sunrise_Alarm_Clock_V2.ino]
2022-09-12 V2.7.3-alpha Temporarily Fixed Bug Causing Weekday to Glitch
    Previously the alarm would show the day of the week but when it changed from Saturday to Sunday the screen would glitch and the day of the week would not be displayed.
    I found that this was because I was using the day() function instead of the weekday() function. The day function actually returns the day of the month and not the day of the week. As a result it was looking for values beyond the size of the daysOfTheWeek array.
    To fix this I changed from using the day() function to using the weekday() function. However, this takes into consideration the month and year. Unfortunately I cannot get the month and year using the NTPClie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
    [Sunrise_Alarm_Clock_V2.ino]
2022-09-12 V2.7.4-alpha Fixed Bug Causing Weekday to Glitch
    I have switched to using a different NTPClient library (included). This library includes the getFormattedDate() function. Using this function I was able to extract the day, month and year which I could then use to set the local time. This ensures that the alarm clock always knows the correct date and therefore it will always display the correct day of the week with no glitches.
    [Sunrise_Alarm_Clock_V2.ino]
2023-08-18 V2.0.2-release Fixed Issue #1: Menu Crash and Memory Usage
    Description:
    It was suspected that the dynamic creation of MenuItem objects was causing the microcontroller to run out of memory and subsequently crash. This issue has been addressed with this update.
    Changes Made:
    - Removed the MenuItem class
    - Removed the Menu class
    - Introduced the MenuItem struct
    - Replaced dynamic creation with fixed-size arrays for MenuItem instances
    Resolves: #1
    [Sunrise_Alarm_Clock_V2.ino]
2023-08-26 V2.0.4-release Added the Device Class
2023-08-27 V2.0.7-release: Improved Code Readability
    In this release, the readability, modularity, and maintainability of the code have been improved through the following changes:
    - **Enhanced Function Portability and Encapsulation:** Arguments have been introduced to several functions to improve their portability and encapsulation. The affected functions include `itIsNight`, `manageOutputs`, `calcNextSync`, and `manageScreenTimeout`.
    - **Code Reusability:** To eliminate redundant code segments, new functions were introduced. Notably, the `displayBlankScreen` and `resetScreenTimeout` functions were created.
    - **Refactored Display-Related Functions:** Display-related functions such as `displayBlankScr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
    [Sunrise_Alarm_Clock_V2.ino]
2023-08-28 V2.0.8-release: Added Device Subclasses
    Separated device behaviour into distinct classes: Device, Alarm, USB, and Light.
    - The Device class handles common functionality such as setting on/off times and checking whether the device should be on or off at a given time.
    - The Alarm class extends Device for alarm-specific features: enable/disable, sounding, and output management.
    - The USB and Light classes inherit from Device, each focusing on their unique behaviours.
    This restructuring enhances code organisation, modularity, and readability.
2023-08-29 V2.0.9-release Fixed Issue #2: On/Off Time Logic
    Previously the logic in `Device::itIsOnTime()` could not handle situations where the device needed to turn on in the evening, and off in the morning (like a phone charging). This was because "onTime > offTime" and therefore "onTime <= now < offTime" could never be true.
    Now `Device::itIsOnTime()` has been updated to check whether "onTime > offTime", and if so, check if it is either after the on time at night, or before the off time in the morning.
    Resolves: #2
